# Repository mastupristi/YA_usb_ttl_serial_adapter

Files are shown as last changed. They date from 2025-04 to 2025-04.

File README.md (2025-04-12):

# USB-TTL Adapter with Auto Voltage Sensing

This is a simple open hardware project for a USB-to-TTL serial adapter based on the FTDI FT232RNL chip. The main feature of this adapter is its automatic voltage level detection, supporting TTL I/O levels from 1.8V to 5V without requiring manual jumper selection.

## Motivation

There are many USB-to-TTL adapters available on the market, such as:

- [AZDelivery FT232RL Adapter](https://www.amazon.it/AZDelivery-FT232RL-Adattatore-convertitore-Gratuito/dp/B01N9RZK6I)
- [DSD TECH SH-U09C2 Adapter](https://www.amazon.it/DSD-TECH-SH-U09C2-Adattatore-Programmazione/dp/B07TXVRQ7V/)

However, most of them require the user to manually set the voltage level using jumpers or switches. This can be inconvenient or even risky if the user forgets to set, or does not know exactly the correct voltage, potentially damaging the target device.

## Key Features

- Based on **FTDI FT232RNL** USB-serial bridge.
- Supports **1.8V to 5V TTL I/O levels**.
- **No jumpers or switches** required to select voltage.
- Uses **TI TXU0202** dual-channel voltage level translator for automatic level adaptation.
- Only **RX** and **TX** signals are used (no RTS/CTS or other control signals).
- Two mirrored TTL connectors with **inverted RX/TX** pinout for flexible wiring
- All schematic symbols and footprints have fields populated for **automated assembly on [JLCPCB](https://jlcpcb.com/)**

## Auto Voltage Detection

This adapter eliminates the need for manual voltage configuration. Thanks to the TXU0202 level shifter, the adapter automatically adapts to the voltage of the connected target device. This makes it safer and easier to use, especially when working with multiple devices operating at different logic levels.

## TTL Pinout

The board provides **two 1x4 pin headers** on the TTL side, with the same signals but **mirrored RX/TX orientation**. This simplifies usage with different target pinouts.

### Pinout (both connectors):

```
[ VCC_TTL | TX | RX | GND ]  ← Connector A
[ VCC_TTL | RX | TX | GND ]  ← Connector B (mirrored)
```

This layout helps avoid the common issue of crossed RX/TX lines between the adapter and the target device.

There are indications in the silkscreen to identify the VCC_TTL and GND pins.

## Manufacturing Support

This project includes files suitable for production with **[JLCPCB](https://jlcpcb.com/)**:

- [usb_uart_1V8_bom_top.csv](usb_uart_1V8_bom_top.csv) and [usb_uart_1V8_bom_bot.csv](usb_uart_1V8_bom_bot.csv): Bill of materials, with fields compatible with JLCPCB's parts selection tool (only **top** side populated)
- [usb_uart_1V8_cpl_top.csv](usb_uart_1V8_cpl_top.csv) and [usb_uart_1V8_cpl_bot.csv](usb_uart_1V8_cpl_bot.csv): Pick-and-place files (only **top** side contains components)
- All schematic symbols and footprints include **LCSC part numbers**, **JLC footprints** and assembly attributes

## Design Tools

This project was developed using **KiCad 9.0.1**.

## Repository Contents

- KiCad design files are on he root dir of the repo
- `usb_uart_1V8.pretty/`: local footprint library
- `gerber/`: Production-ready Gerber + drill files, packed in [grb_usb_uart_1V8.zip](gerber/grb_usb_uart_1V8.zip)

## Photos

Here is a photo of of of the assembled board in revision v0.1

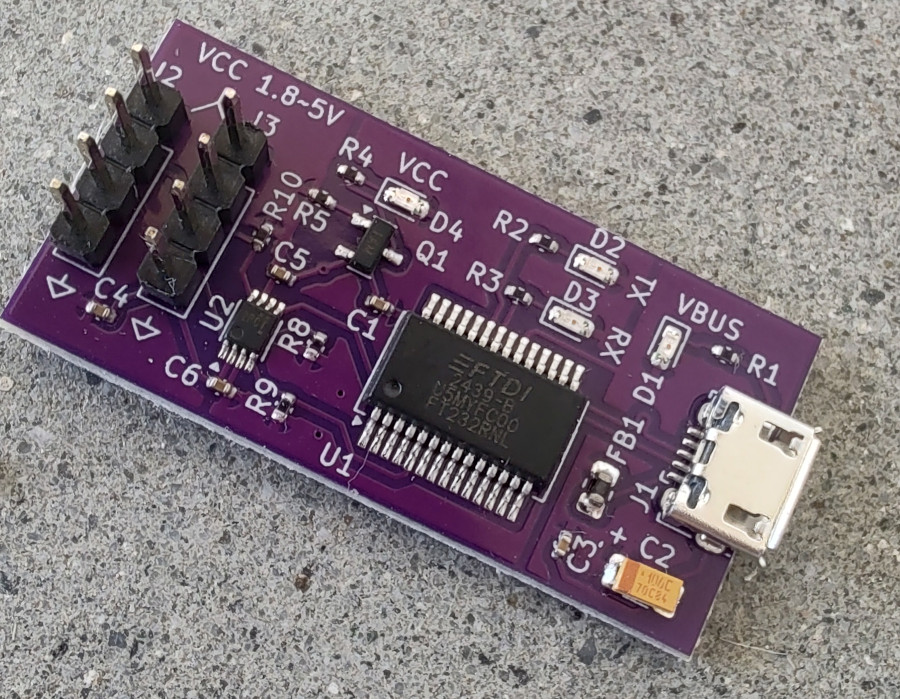
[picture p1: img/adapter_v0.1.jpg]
v0.1


## License

This project is licensed under the **CERN-OHL-S v2** open hardware license.
See [LICENSE.CERN-OHL-S_v2.txt](LICENSE) for more information.

## How to Contribute

Feel free to open issues or submit pull requests if you find bugs or want to suggest improvements.

## Acknowledgments

This project was inspired by the analysis in this blog post:
[https://www.electrothinks.com/2024/02/ft232rl-usb-to-serial-uart-module.html](https://www.electrothinks.com/2024/02/ft232rl-usb-to-serial-uart-module.html)

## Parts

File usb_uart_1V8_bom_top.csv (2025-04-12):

Comment | Designator | Footprint | LCSC Part #
100nF | C1 C3 C4 C5 C6 | 0402 | C1525
10uF | C2 | CASE-A-3216-18(mm) | C7171
NCD0805R1 | D1 D2 D3 D4 | 0805 | C84256
GZ2012D601TF | FB1 | 0805 | C1017
USB_B_Micro | J1 | SMD | C132563
Conn_02x04_Odd_Even | J2
MMBT3904 | Q1 | SOT-23 | C20526
1k5 | R1 | 0603 | C22843
270 | R2 R3 | 0603 | C22966
10k | R4 R5 R6 | 0402 | C25744
470 | R7 | 0603 | C23179
47k | R8 | 0603 | C25819
FT232RNL | U1 | SSOP-28 | C5246810
TXU0202DCU | U2 | VSSOP-8 | C5186957

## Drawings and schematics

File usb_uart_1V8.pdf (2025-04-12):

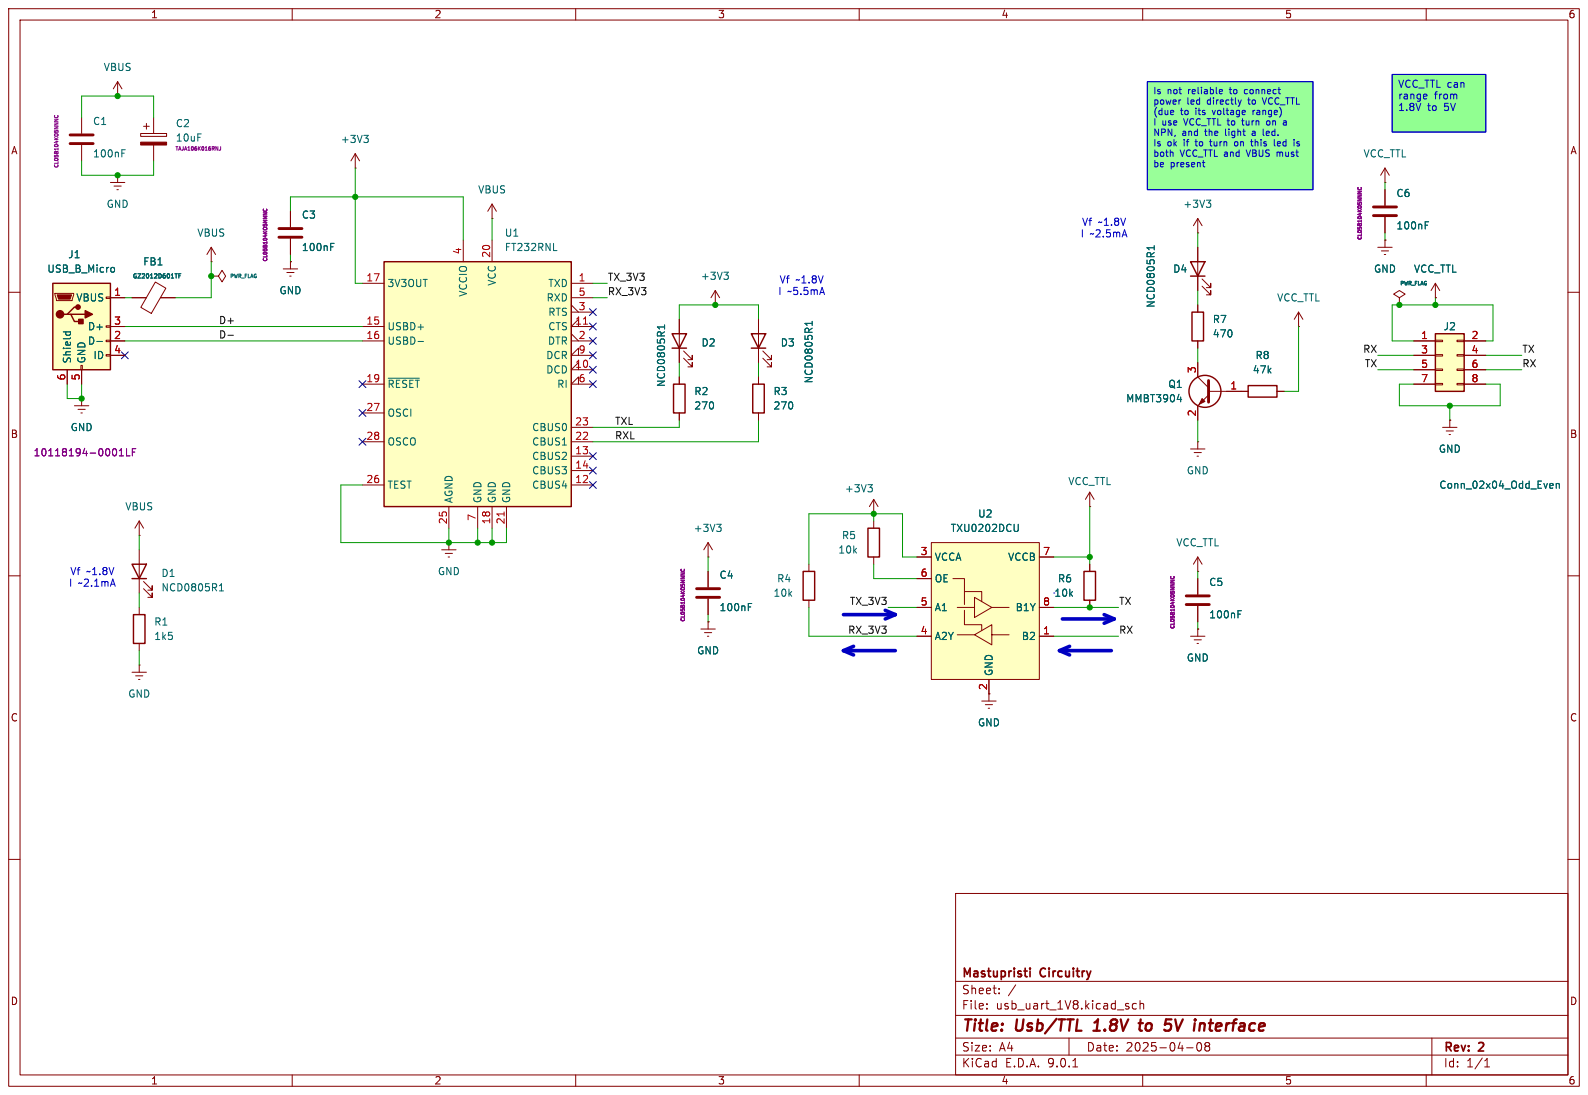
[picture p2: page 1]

(due to its voltage range)
I use VCC_TTL to turn on a NPN, and the light a led.

7 VCC 20 GND 18 GND 21 TXD 1 RXD 5 RTS 3 CTS 11 DTR 2 DCR 9 DCD 10 RI 6 CBUS0 23 CBUS1 22 CBUS2 13 CBUS3 14 CBUS4 12 U1 FT232RNL VBUS D2 NCD0805R1

File: usb_uart_1V8.kicad_sch Sheet: / Mastupristi Circuitry

Id: 1/1 Title: Usb/TTL 1.8V to 5V interface

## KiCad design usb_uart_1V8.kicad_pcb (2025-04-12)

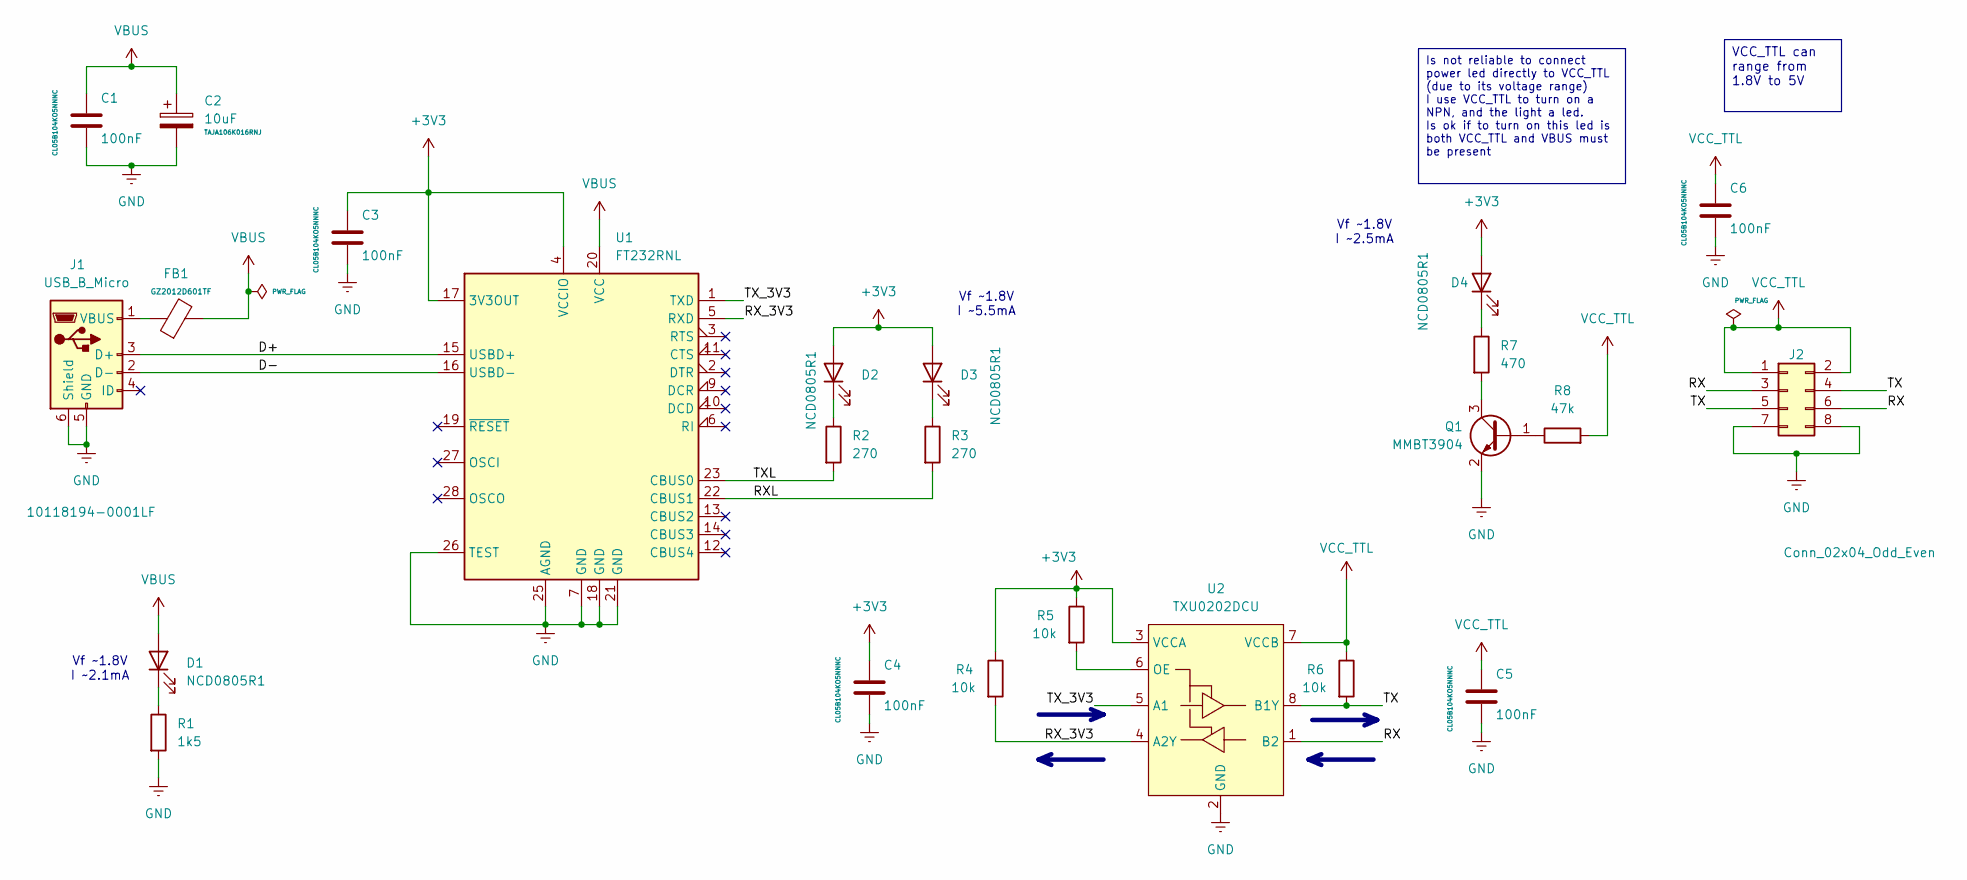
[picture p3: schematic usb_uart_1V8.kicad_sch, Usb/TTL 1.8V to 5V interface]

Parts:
C1, C3, C4, C5, C6: 100nF; C_0402_1005Metric; JLCPCB Part# C1525
C2: 10uF; C_1206_3216Metric; JLCPCB Part# C7171
D1, D2, D3, D4: NCD0805R1; LED_0805_2012Metric; JLCPCB Part# C84256
FB1: GZ2012D601TF; R_0805_2012Metric; JLCPCB Part# C1017
J1: USB_B_Micro; USB_Micro-B_Amphenol_10118194-0001LF_Horizontal; JLCPCB Part# C132563
J2: Conn_02x04_Odd_Even; PinHeader_2x04_P2.54mm_Vertical
Q1: MMBT3904; SOT-23; JLCPCB Part# C20526
R1: 1k5; R_0603_1608Metric_Pad0.98x0.95mm_HandSolder; JLCPCB Part# C22843
R2, R3: 270; R_0603_1608Metric_Pad0.98x0.95mm_HandSolder; JLCPCB Part# C22966
R4, R5, R6: 10k; R_0402_1005Metric_Pad0.72x0.64mm_HandSolder; JLCPCB Part# C25744
R7: 470; R_0603_1608Metric_Pad0.98x0.95mm_HandSolder; JLCPCB Part# C23179
R8: 47k; R_0603_1608Metric_Pad0.98x0.95mm_HandSolder; JLCPCB Part# C25819
U1: FT232RNL; SSOP-28_5.3x10.2mm_P0.65mm; JLCPCB Part# C5246810
U2: TXU0202DCU; VSSOP-8_2.3x2mm_P0.5mm; JLCPCB Part# C5186957

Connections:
+3V3: C3.1, C4.1, D2.2 (A), D3.2 (A), D4.2 (A), R4.1, R5.1, U1.4 (VCCIO), U1.17 (3V3OUT), U2.3 (VCCA)
/D+: J1.3 (D+), U1.15 (USBD+)
/D-: J1.2 (D-), U1.16 (USBD-)
/RX: J2.3, J2.6, U2.1 (B2)
/RXL: R3.2, U1.22 (CBUS1)
/RX_3V3: R4.2, U1.5 (RXD), U2.4 (A2Y)
/TX: J2.4, J2.5, R6.2, U2.8 (B1Y)
/TXL: R2.2, U1.23 (CBUS0)
/TX_3V3: U1.1 (TXD), U2.5 (A1)
GND: C1.2, C2.2, C3.2, C4.2, C5.2, C6.2, J1.5 (GND), J1.6 (Shield), J2.7, J2.8, Q1.2 (E), R1.2, U1.7 (GND), U1.18 (GND), U1.21 (GND), U1.25 (AGND), U1.26 (TEST), U2.2 (GND)
unnamed: D1.1 (K), R1.1
unnamed: D2.1 (K), R2.1
unnamed: D3.1 (K), R3.1
unnamed: D4.1 (K), R7.1
unnamed: FB1.1, J1.1 (VBUS)
unnamed: Q1.1 (B), R8.1
unnamed: Q1.3 (C), R7.2
unnamed: R5.2, U2.6 (OE)
VBUS: C1.1, C2.1, D1.2 (A), FB1.2, U1.20 (VCC)
VCC_TTL: C5.1, C6.1, J2.1, J2.2, R6.1, R8.2, U2.7 (VCCB)

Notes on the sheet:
Vf ~1.8V I ~2.5mA
Vf ~1.8V I ~2.1mA
Vf ~1.8V I ~5.5mA
VCC_TTL can range from 1.8V to 5V
Is not reliable to connect power led directly to VCC_TTL (due to its voltage range) I use VCC_TTL to turn on a NPN, and the light a led. Is ok if to turn on this led is both VCC_TTL and VBUS must be present

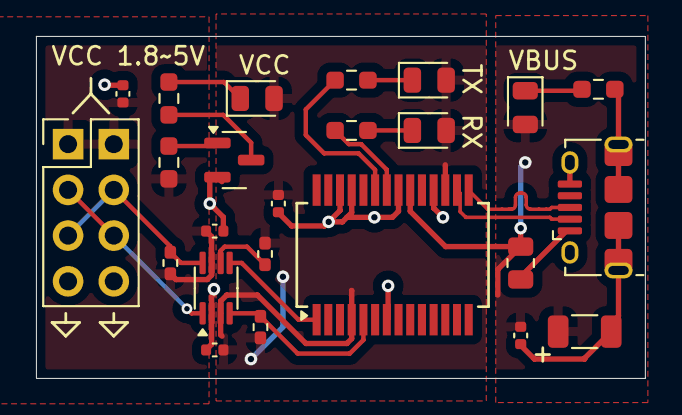
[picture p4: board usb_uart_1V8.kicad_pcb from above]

Board: 2 copper layers, 33.8 x 19.0 mm, 24 parts (0 on the bottom side), 20 nets.

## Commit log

2025-03-29 [ADD] first import
    [usb_uart_1V8.kicad_pcb, usb_uart_1V8.kicad_sch]
2025-03-30 [UPG] ft232 supplied by 5V3 and added level shifter
    [usb_uart_1V8.kicad_sch]
2025-03-30 [UPG] pcb
    [usb_uart_1V8.kicad_pcb]
2025-03-30 [UPG] almost finished PCB
    [usb_uart_1V8.kicad_pcb]
2025-03-31 [UPG] level shifter: 2 become 1
    [usb_uart_1V8-B_Cu.gbl, usb_uart_1V8-B_Mask.gbs, usb_uart_1V8-B_Paste.gbp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]
2025-04-08 [CLN] cleanup
    [usb_uart_1V8.csv]
2025-04-12 [UPG] ver 0.4
    - changed some values
    - PN basic from JLCPCB
    - reduced dimension
    - changed some components, now are bigger, eg. 0402 -> 0603
    - used handsolder footprint for fome resistor
    - changed led (less efficient)
    [usb_uart_1V8-B_Cu.gbl, usb_uart_1V8-B_Mask.gbs, usb_uart_1V8-B_Paste.gbp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]
